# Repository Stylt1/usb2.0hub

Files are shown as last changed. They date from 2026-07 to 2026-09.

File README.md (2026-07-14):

View this project on [CADLAB.io](https://cadlab.io/project/30472). 

# usb2.0hub

3D Renders:
Snímek obrazovky 2026-07-14 v 21 36 32
Snímek obrazovky 2026-07-14 v 21 35 33
Snímek obrazovky 2026-07-14 v 21 34 42

## 🚀 USB 2.0 High-Speed Hub

This project is a custom-designed **4-port USB 2.0 hub** built around the WCH CH334F controller. It is optimized for stable data transmission and reliable power distribution.

### ⚡ Core Specifications
* **Protocol:** USB 2.0 High-Speed
* **Transfer Rate:** Up to 480 Mbps
* **Controller IC:** CH334F
* **Upstream Port:** 1x USB [Type-C] (Connection to PC/Host)
* **Downstream Ports:** 4x USB [Type-A] (Connection for peripherals)

### 🛠️ PCB Design & Stackup
To ensure signal integrity and proper 90Ω differential impedance for the USB data lines, the board is designed as a **4-layer PCB**. 

**Layer Stackup:**
1. **Top Layer:** Signal (Main high-speed routing and components)
2. **Inner Layer 1:** GND Plane (Solid ground reference)
3. **Inner Layer 2:** Power Plane (Power distribution)
4. **Bottom Layer:** Second Signal (Low-speed routing and signal crossovers)

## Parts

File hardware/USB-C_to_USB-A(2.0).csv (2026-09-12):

Reference | Qty | Value | DNP | Exclude from BOM | Exclude from Board | Footprint | Datasheet
C1,C6,C10,C15,C19 | 5 | 10nF |  |  |  | Capacitor_SMD:C_0603_1608Metric
C2,C3,C5,C7,C9,C11,C13,C14,C17,C18,C20,C22 | 12 | 100nF |  |  |  | Capacitor_SMD:C_0603_1608Metric
C4,C8,C12,C16,C21 | 5 | 10uF |  |  |  | Capacitor_SMD:C_1206_3216Metric
D1,D2,D3,D4 | 4 | LED |  |  |  | LED_SMD:LED_0603_1608Metric
F1 | 1 | 2.0A |  |  |  | Fuse:Fuse_1210_3225Metric
J1 | 1 | USB_C_Receptacle_USB2.0_16P |  |  |  | Connector_USB:USB_C_Receptacle_XKB_U262-16XN-4BVC11 | https://www.usb.org/sites/default/files/documents/usb_type-c.zip
J2,J3,J4,J5 | 4 | USB_A |  |  |  | Connector_USB:USB_A_Molex_48037-2200_Horizontal
R1 | 1 | 10K |  |  |  | Resistor_SMD:R_0603_1608Metric
R2,R9,R10,R11,R12 | 5 | 1M |  |  |  | Resistor_SMD:R_0603_1608Metric
R3,R4 | 2 | 5K1 |  |  |  | Resistor_SMD:R_0603_1608Metric
R5,R6,R7,R8 | 4 | 330R |  |  |  | Resistor_SMD:R_0603_1608Metric
U1 | 1 | CH334F |  |  |  | Package_DFN_QFN:QFN-24-1EP_4x4mm_P0.5mm_EP2.7x2.7mm | https://www.wch-ic.com/downloads/file/327.html
U2,U3,U4,U5,U6 | 5 | USBLC6-2SC6 |  |  |  | Package_TO_SOT_SMD:SOT-23-6 | https://www.st.com/resource/en/datasheet/usblc6-2.pdf

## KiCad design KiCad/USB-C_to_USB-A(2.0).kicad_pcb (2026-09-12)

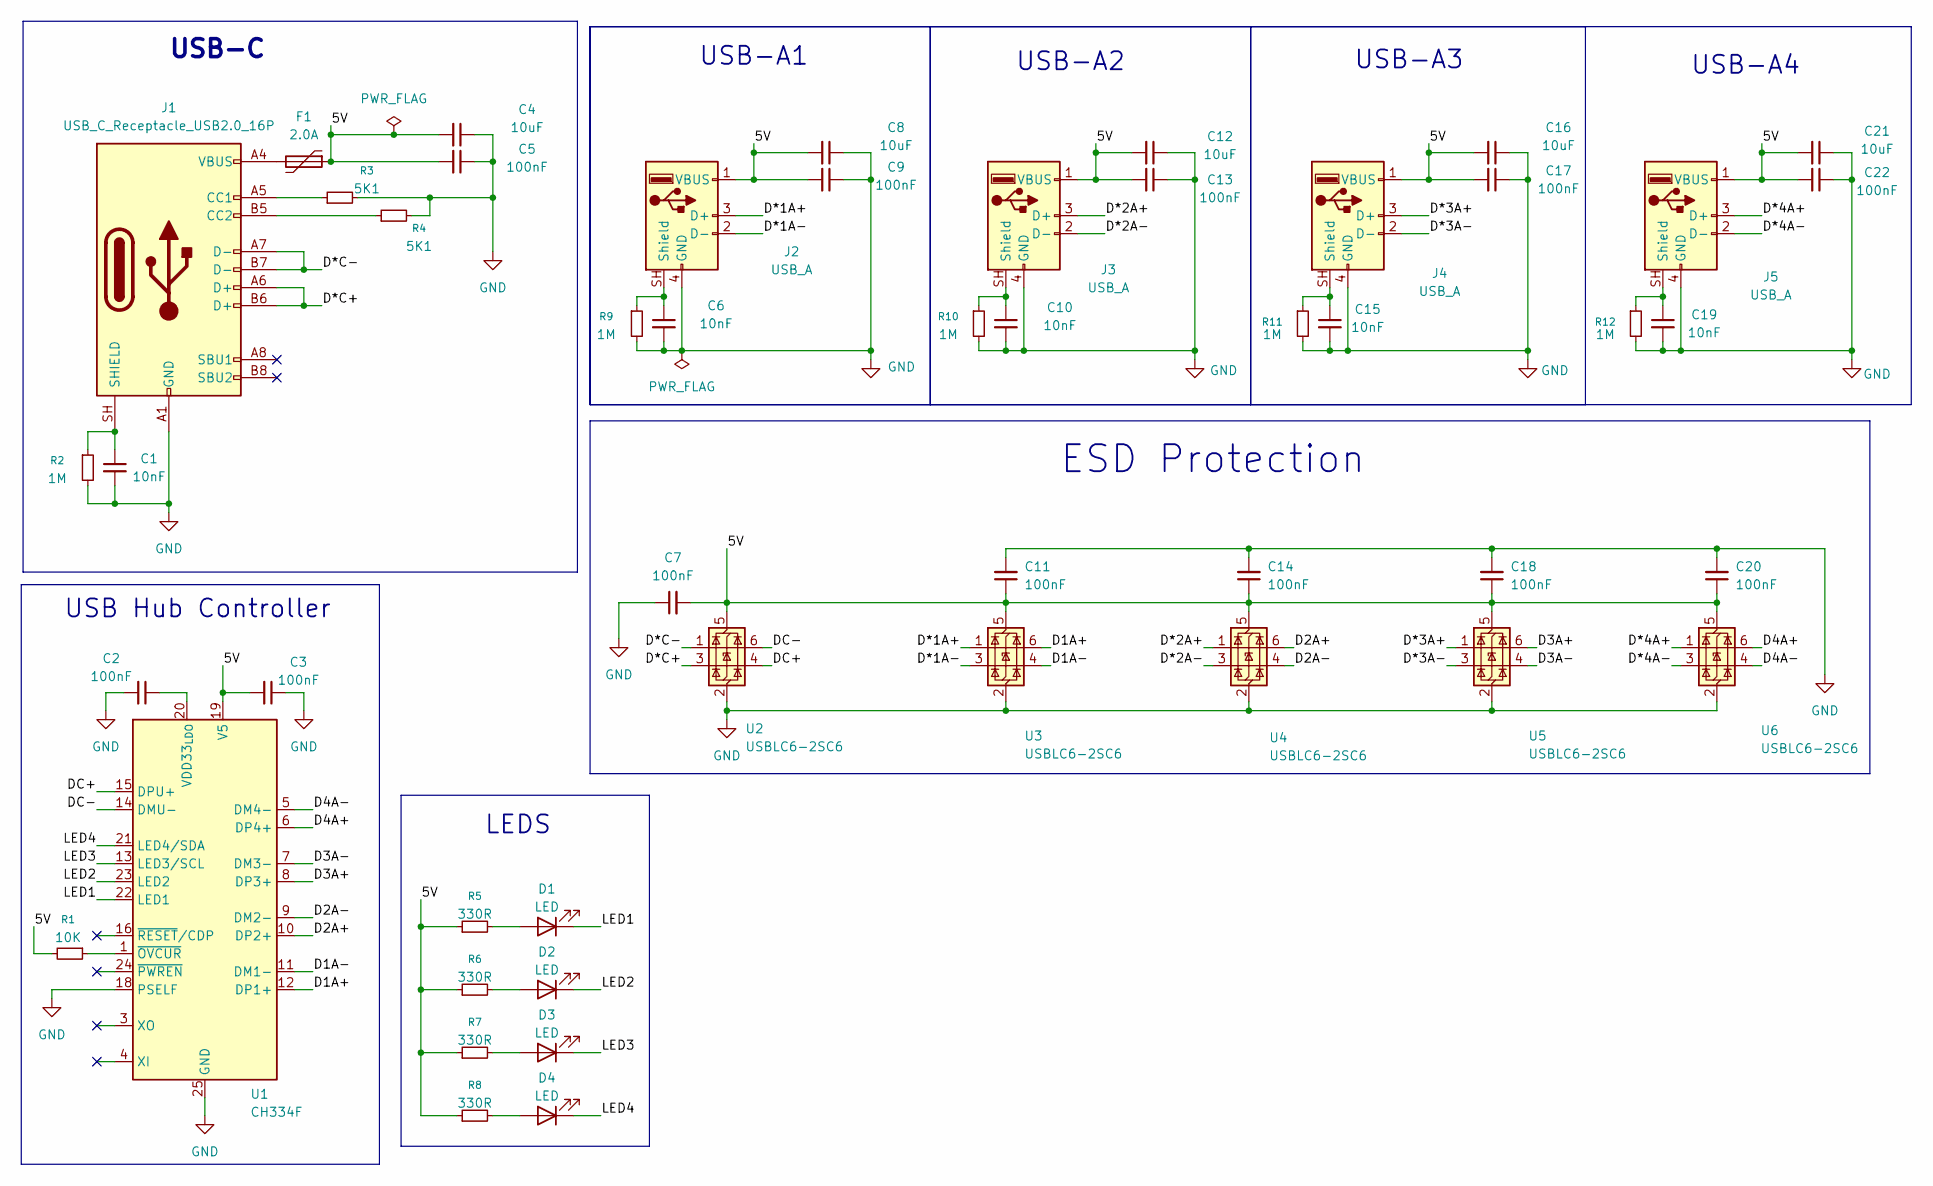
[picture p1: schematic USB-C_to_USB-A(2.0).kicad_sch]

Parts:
C1, C6, C10, C15, C19: 10nF; C_0603_1608Metric
C2, C3, C5, C7, C9, C11, C13, C14, C17, C18, C20, C22: 100nF; C_0603_1608Metric
C4, C8, C12, C16, C21: 10uF; C_1206_3216Metric
D1, D2, D3, D4: LED; LED_0603_1608Metric
F1: 2.0A; Fuse_1210_3225Metric
J1: USB_C_Receptacle_USB2.0_16P; USB_C_Receptacle_XKB_U262-16XN-4BVC11
J2, J3, J4, J5: USB_A; USB_A_Molex_48037-2200_Horizontal
R1: 10K; R_0603_1608Metric
R2, R9, R10, R11, R12: 1M; R_0603_1608Metric
R3, R4: 5K1; R_0603_1608Metric
R5, R6, R7, R8: 330R; R_0603_1608Metric
U1: CH334F; QFN-24-1EP_4x4mm_P0.5mm_EP2.7x2.7mm
U2, U3, U4, U5, U6: USBLC6-2SC6; SOT-23-6

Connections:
/5V: C3.2, C4.2, C5.2, C7.2, C8.2, C9.2, C11.1, C12.2, C13.2, C14.1, C16.2, C17.2, C18.1, C20.1, C21.2, C22.2, F1.1, J2.1 (VBUS), J3.1 (VBUS), J4.1 (VBUS), J5.1 (VBUS), R1.2, R5.1, R6.1, R7.1, R8.1, U1.19 (V5), U2.5 (VBUS), U3.5 (VBUS), U4.5 (VBUS), U5.5 (VBUS), U6.5 (VBUS)
/D1A+: U1.12 (DP1+), U3.6 (I/O1)
/D1A-: U1.11 (DM1-), U3.4 (I/O2)
/D2A+: U1.10 (DP2+), U4.6 (I/O1)
/D2A-: U1.9 (DM2-), U4.4 (I/O2)
/D3A+: U1.8 (DP3+), U5.6 (I/O1)
/D3A-: U1.7 (DM3-), U5.4 (I/O2)
/D4A+: U1.6 (DP4+), U6.6 (I/O1)
/D4A-: U1.5 (DM4-), U6.4 (I/O2)
/D*1A+: J2.3 (D+), U3.1 (I/O1)
/D*1A-: J2.2 (D-), U3.3 (I/O2)
/D*2A+: J3.3 (D+), U4.1 (I/O1)
/D*2A-: J3.2 (D-), U4.3 (I/O2)
/D*3A+: J4.3 (D+), U5.1 (I/O1)
/D*3A-: J4.2 (D-), U5.3 (I/O2)
/D*4A+: J5.3 (D+), U6.1 (I/O1)
/D*4A-: J5.2 (D-), U6.3 (I/O2)
/D*C+: J1.A6 (D+), J1.B6 (D+), U2.3 (I/O2)
/D*C-: J1.A7 (D-), J1.B7 (D-), U2.1 (I/O1)
/DC+: U1.15 (DPU+), U2.4 (I/O2)
/DC-: U1.14 (DMU-), U2.6 (I/O1)
/LED1: D1.1 (K), U1.22 (LED1)
/LED2: D2.1 (K), U1.23 (LED2)
/LED3: D3.1 (K), U1.13 (LED3/SCL)
/LED4: D4.1 (K), U1.21 (LED4/SDA)
GND: C1.2, C2.2, C3.1, C4.1, C5.1, C6.2, C7.1, C8.1, C9.1, C10.2, C11.2, C12.1, C13.1, C14.2, C15.2, C16.1, C17.1, C18.2, C19.2, C20.2, C21.1, C22.1, J1.A1 (GND), J1.A12 (GND), J1.B1 (GND), J1.B12 (GND), J2.4 (GND), J3.4 (GND), J4.4 (GND), J5.4 (GND), R2.2, R3.2, R4.2, R9.2, R10.2, R11.2, R12.2, U1.18 (PSELF), U1.25 (GND), U2.2 (GND), U3.2 (GND), U4.2 (GND), U5.2 (GND), U6.2 (GND)
unnamed: D1.2 (A), R5.2
unnamed: D2.2 (A), R6.2
unnamed: D3.2 (A), R7.2
unnamed: D4.2 (A), R8.2
unnamed: F1.2, J1.A4 (VBUS), J1.A9 (VBUS), J1.B4 (VBUS), J1.B9 (VBUS)
unnamed: J1.A5 (CC1), R3.1
unnamed: J1.B5 (CC2), R4.1
unnamed: C1.1, J1.SH (SHIELD), R2.1
unnamed: C6.1, J2.SH (Shield), R9.1
unnamed: C10.1, J3.SH (Shield), R10.1
unnamed: C15.1, J4.SH (Shield), R11.1
unnamed: C19.1, J5.SH (Shield), R12.1
unnamed: C2.1, U1.20 (VDD33_{LDO})
unnamed: R1.1, U1.1 (~OVCUR)

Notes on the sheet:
USB-A3
LEDS
USB-A2
ESD Protection
USB-A4
USB-C
USB Hub Controller
USB-A1

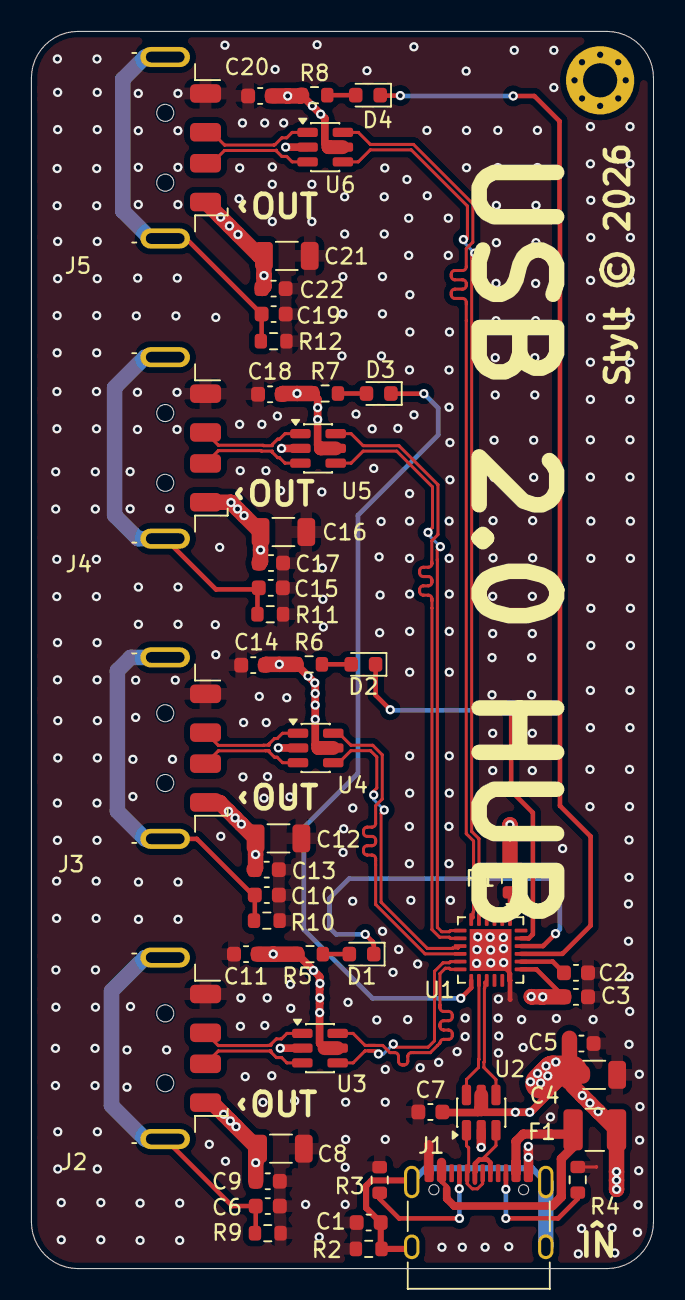
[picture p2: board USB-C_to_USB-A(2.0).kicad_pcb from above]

Board: 4 copper layers, 40.1 x 79.8 mm, 50 parts (0 on the bottom side), 40 nets.

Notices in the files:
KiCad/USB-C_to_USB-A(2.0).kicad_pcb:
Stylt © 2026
